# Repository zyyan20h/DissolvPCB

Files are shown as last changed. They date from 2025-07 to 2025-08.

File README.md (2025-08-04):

# DissolvPCB 
### Fully Recyclable Electronics with Liquid Metal Conductors and 3D-Printed PVA Substrates
DissolvPCB is a fully recyclable printed circuit board assembly (PCBA) manufacturing technique 
that utilizes affordable FDM 3D printing with Polyvinyl Alcohol (PVA) as a water-soluble substrate 
and eutectic gallium-indium (EGaIn) as the conductive material. 

This Github repository contains the Python macro component used during the DissolvPCB fabrication process. 
The macro enables users to design custom PCB assemblies using standard practices, then automatically
convert the design into a 3D model ready to be printed. Also included are some PCB design examples that 
were used for the demonstration of the DissolvPCB fabrication process. 
Listed below are the prerequisites and instructions on how to utilize this tool. 
Detailed instructions on the entire DisssolvPCB fabrication process can be found under [DissolvPCB Processs Details](DissolvPCB_Process_Details.md).

teaser_labelless

Please see the [paper](https://www.arxiv.org/abs/2507.22193) for more details on development, implementation, and evaluation of DissolvPCB, and if you use DissolvPCB in your work, please consider to cite the following paper:
```
@article{yan2025dissolvpcb,
  title={DissolvPCB: Fully Recyclable 3D-Printed Electronics with Liquid Metal Conductors and PVA Substrates},
  author={Yan, Zeyu and Hong, SuHwan and Hester, Josiah and Cheng, Tingyu and Peng, Huaishu},
  publisher = {Association for Computing Machinery},
  url = {https://doi.org/10.1145/3746059.3747604},
  year={2025}，
  booktitle = {Proceedings of the 38th Annual ACM Symposium on User Interface Software and Technology}
}
```

## Installation 

### Prerequisites
  - Python 3.0.0 or above
  - FreeCAD 1.0.0 or above
    - https://www.freecad.org/downloads.php
  - KiCAD 8.0.7 or above
    - https://www.kicad.org/download/

### KiCAD Libraries Installation
  - Add Symbol Library
    - Located in /libray/PVA_board.kicad_sym
    - Add by going to: Symbol Editor -> File -> Add Library
  - Add Footprint Library
    - Located in /library/PVA_board.pretty
    - Add by going to: Footprint Editor -> File -> Add Library
  - Copy 3D moddels to KiCAD 3D Models
    - Copy the folder /library/PVA_Board_3Dmodels into directory
    - Set Global Variable "KICAD_3DMODEL_DIR" to correct directory
      - Usually Located under C:\Program Files\KiCad\8.0\share\kicad\3dmodels
      - You can locate the direcotry by going to the KiCAD project window, then Preferences -> Configure Paths
   
## DissolvPCB Design in KiCAD
### PCB Schematic Design
  If you have imported the libraries as described above, the schematic design follows standard procedues.
  During the footprint assignment at the end of your schematic design procecss, verify that 
  footprints are from the PVA_Board library.
    
### PCB Layout Design
  To ensure compatibility with the DissolvPCB fabrication process, a few settings must be changed first. 
  The DRC settings can simply be imported from /KiCAD/DRC_Import_Prj/DRC_Import/DRC_Import.kicad_pcb, using the "Import Settings from Another Board" button under File -> Board Setup. 
  By importing "Design rule constraints", "Predefined track & via dimensions", and "Violation severities" (optional), 
  the PCB design will become compatible with the DissolvPCB fabrication process. (See attached below)
	432048682-aeb7e37b-99a9-4a01-ab0c-9ea9d6ce369a

## Macro Execution
FreeCAD has built-in support for Python macros. 
To run, open the Python script by going to File -> Open and open /Python/create.py.
Then, run the macro by going to Macro -> Run Macro. 
Note that the boolean process step at the end can take some time depending on the complexity of your design and your compute power. 
Therefore, it is recommended that you run the macro on a system with a more powerful CPU if possible.

### Macro Functions
The Python scripts contain code comments throughout to help users debug and modify. Overall, the 4 main steps of the macro includes:
- Trace & Pad Generation
- DissolvPCB Body Creation
- 3D Footprint Insertion
- Boolean Operation

Except for the Boolean Operation, these parts are independant of each other. 
Thus, it is possible to run any combination of of the first 3 as desired. 

*Note: If the boolean operation fails from an error relating to 'multiple bodies', you may have to enable a setting. 
Go to Edit -> Preferences -> Part/Part Design -> Experimental -> check "Allow multiple solids in Part Design Body by Defualt"

## Examples 

Some KiCAD Designs are provided, which are listed below.
Note that Circuit_sample_01, circuit_sample_02, and ESP_Speaker designs are directly compatible with the macro, and does not require any modifications to replicate our designs. 
  - /KiCAD/circuit_sample/circuit_sample_01
    - Hall Sensor & ATTiny85 design, used throughout the paper
      
  - /KiCAD/circuit_sample/circuit_sample_02
    - Identical Hall Sensor & ATTiny85 design, but with different board outline
	- /KiCAD/circuit_sample/recycled_driver
		- Motor driver circuit design, used to demonstrate the capabilities of the recycled PVA filament
  - /KiCAD/ESP_Breakout
    - Breakout board(s) designed to house the ESP32 board used for the ESP_Speaker Design
    - The version utilized on the paper is the "2mm_2row_esp_breakout" design
  - /KiCAD/ESP_Speaker
    - ESP32-based bluetooth speaker design.
    - The exact design used on the paper demo is "rev_2_ESP_Speaker_2row_esp"
    - Alternatively, a design with components only on one side is under "rev_3_ESP_Speaker_2row_esp"
      
  - /KiCAD/fidget
    - Fidget toy example used on the paper, utilizing a 3D circuit design process.


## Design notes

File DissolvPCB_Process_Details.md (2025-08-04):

# DissolvPCB 
### Fully Recyclable Electronics with Liquid Metal Conductors and 3D-Printed PVA Substrates
This document the full work flow of creating a circuit board based on the DissolvPCB process in detail, along with tips, recommendations, and general cautions. 
This guide will instruct users through the steps of printing and preparation, assembling, and recycling, as highlighted in the figure below. 

teaser_labelless

# DissolvPCB Printing & Preparation
## Materials 
- In addition to things like 3D printers and EGaIn, other materials and tools needed for the DissolvPCB fabrication process are:
	- PPE - Gloves, Goggles
 	- Wet wipes (Such as Clorox)
  	- Magnetic Stirrers
  	- Glass Beakers
  	- Scale
  	- Syringe
  	- Fine Tweezers
  	  
		

## DissolvPCB Printing
### PVA Nozzle 
- Size
  	- A nozzle size of 0.2 mm is recommended for the smallest possible feature size, trace dimensions, layer detail, etc.
  	- A 0.4 mm nozzle may be used, although some dimensions may have to be increased and the finest pitch components may not be as feasible.
  		In this case, 0.85 mm traces are recommended instead of the default 0.75 mm.
- Cleanup
    - Nozzle Storage
    	- After printing with PVA, it is recommended PLA is loaded into the filament in place and any leftover PVA be extruded out.
  		- As is standard, the unloaded PVA filament should be kept in a filament dryer.
    - Nozzle Cleanout
  		- In cases where the entire nozzle needs to be cleaned, it could be submerged in water to remove any remaining PVA.

### PVA Print Storage
- Moisture Control
    - Filament Dryer should be used whenever possible for the storage of filaments, prints, and finished circuits to avoid moisture damage.
    - If at any point of the DissolvPCB assembly the circuit gets moisture damaged, it can be reversed in most cases in a dryer. Slight changes like warping may remain to some degree.
		
## EGaIn Preparation 

### EGaIn Viscosity Control 
- Oxidation Level
	- The viscosity of the liquid metal is controlled by the oxidation level of EGaIn.
	- EGaIn is very liquid at room temperature. If a thicker consistency is desired, the EGaIn can be oxidized using the magnetic stirrer.
		(Over the air exposure with periodic stirring will work, just slower)
- Viscosity Control
	- EGaIn viscosity can be fine tuned by mixing unoxidized EGaIn in appropriate ratios until the desired consistency is achieved.
   
		

### EGaIn Storage and Collection 
- General Storage
	- EGaIn should be stored in neutral constainers, such as glass beakers.
		If EGaIn is being stored period of time longer than an hour, a lid is recommended to prevent unwanted oxidation.
	- For long term storage, plastic paint containers may be a good alternative.
		A good sealing lid is essential.

		

- Collection
	- In most cases, EGaIn can easily be collected using a syringe or a pipette.

   		
	- In rare cases where the EGaIn is too thick to be sucked into a syringe, the EGaIn may have to be scooped into the syringe bit by bit.
- EGaIn Recollection ('dump')
    - Having a small beaker of Sodium Hyroxide solution readily available is highly recommended.
    - Any excess EGaIn can be easily collected into one container, while the NaOH solution deoxidizes them, ready for recollection and reuse.
 
### Safety and Cautions
- PPE
	- Gloves and Goggles are a must.
 	- Lab coats may be desireable in case of spills.
- Cautions
	- Small bits of EGaIn may remain on any surface and can spread easily if caution is not taken.
 	- Wet wipes (as pictured) can be a great tool to pick up EGaIn on any surface for cleaning.
  	- Always keep a seperate station dedicated to anything involved with EGaIn.

# DissolvPCB Assembly
## EGaIn
### EGaIn Injection
- Syringe Tip
	- Make sure the tip is clear of any obstruction before attaching to a syringe.
	- The syringe tip can be stored in the NaOH solution after use to remove any leftover EGaIn.
- What is a 'good' injection?
    - A slightly concave shape is desired, as excessive EGaIn can cause shorts and spills.

	

### Safety & Cautions
- PPE
	- Gloves and Goggles are a must.
 	- Lab coats may be desireable in case of spills.
- Cautions
	- Be weary of potential spills being directed towards the body, especially the face.
 	- Slow, fine manipulation of the EGaIn syringe is recommended, as EGaIn injection takes little to no force.
	- Excessive injections on the print or syringe can be collected into the NaOH solution beaker.
 		Here, the wet wipes can be used to 'wipe' execessive EGaIn into the beaker.
	- When placing components later, checking the EGaIn for proper contact may be necessary.

## Component Assembly
### Component Placement
- Component can be gently seated into its respective sockets once EGaIn is injected.
	A light push may be needed to ensure proper seating.

 	
 
### Component PVA Glue 
- The purpose of PVA glue is to:
  - Hold components in place
  - Prevent EGaIn spills
- Cautions
  - PVA glue, especially ones with higher water content, may deform the circuit body slightly. 
  - Again, make sure there aren't any short circuits before the glue cures.
- After everything is finished, the circuit can be dried and kept using a filament drier.

  	

# DissolvPCB Recycling

## Component Recovery 

### Dissolving DissolvPCB Assemblies
- Any DissolvPCB assembly may be dissolved simply by dropping it into water.
  The dissolving process can be accelerated using warmer water temperatures and occasional stirring.

  	
   
### Component Recovery
- After DissolvPCB is completely dissolved in water, components can be simply plucked out of the PVA solution.
- Components then can be cleaned and dried, then be ready for reuse.

	

### Safety & Cautions
- PPE
	- Gloves and Goggles are a must.
 	- Lab coats may be desireable in case of spills.
- Cautions
	- Residual PVA and/or EGaIn may remain on surfaces. Take cautions to avoid contamination
    
## EGaIn Recovery 

### EGaIn Collection & De-Oxidation
- Leftover EGaIn can be de-oxidized and re-consolidated easily using a solution of NaOH.
- Afterwards, EGaIn can be collected using a pipette and stored safely until reuse.

  	

### Safety & Disposal 
- After the NaOH solution is used, the basic solution must be neutralized. A safe acidic solution, such as Citric Acid, may be used.
  
## PVA Recovery 

### PVA Recovery - Filter
- The PVA solution should be filtered in case any contaminents are present.
  This also guarentees a cleaner extrusion when recyling the PVA into filament.

	
  
### PVA Recovery - Drying
- The PVA solution can be transferred into a petri dish to dry. A hot plate can be used here to accelerate the drying.

	

### PVA Recovery - PVA Glue
- After a certain moisture content of the PVA solution is reached, it can be used as PVA glue for the next iteration of DissolvPCB.
- Storage of PVA glue in a capped syringe may be appropriate.

	
  
### PVA Recovery - PVA Filament
#### Raw PVA Material Collection
- Dried PVA Sheets
	- By drying the PVA solution all the way, sheets of PVA can be peeled from the container of choice.
		A slightly flexible container can be easier to peel.

	

- Moisture Control
	- Extrusion quality can be heavily impacted by moisture in the processing material.
 		Ensure the filament material is kept dry as possible.
   
- Sheet Processing
	- The PVA sheets should be cut into appropriate sizes for filament extrusion.

#### PVA Recovery - Filament Extrusion
- Extrusion Temperature
	- Extrusion temperature may vary between extruder machines.
		However, extruded material should be a mouldable clay consistency than a liquid.
	- Too low of a temperature can prevent the extruded filament from being stretched to the desired diameter.
	- Too high of a temperature may cause filament deformation and sticking.
   
	
  
 	- It may be helpful to have airflow over the filament to help it hold its shape after being stretched out
- Extrusion of crude filament
	- Depending on the quality of the PVA base material, the extruded filament may be of low quality (such as bubbling).
   	  In this case, the extruded filament needs to be re-cut and processed again for a high-quality filament.
   - If low quality first extrusion is expected, it may help to extrude thicker filament to reduce work in filament processing.
     
	

#### Safety & Cautions
- PPE
	- A mask is highly recommended, gloves may be helpful.
	- Make sure filament extrusion is done in a well-ventilated area.
 		A fume hood, if available, is recommended.

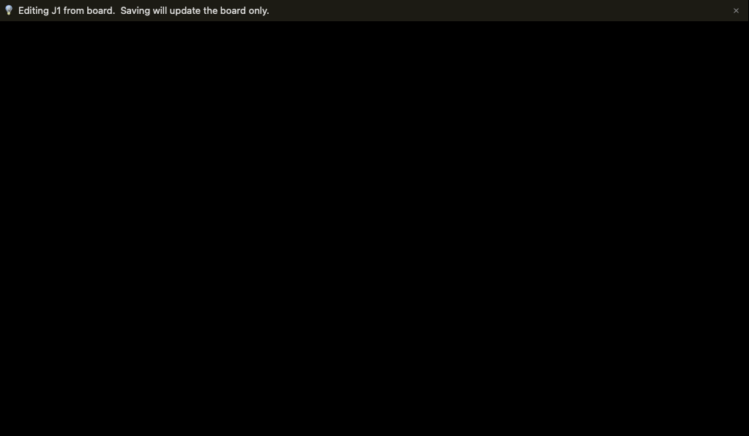
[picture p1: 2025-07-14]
KiCAD/ESP_Speaker/doubleLayer_trial/SAMTEC_USB-B-S-X-X-TH.png

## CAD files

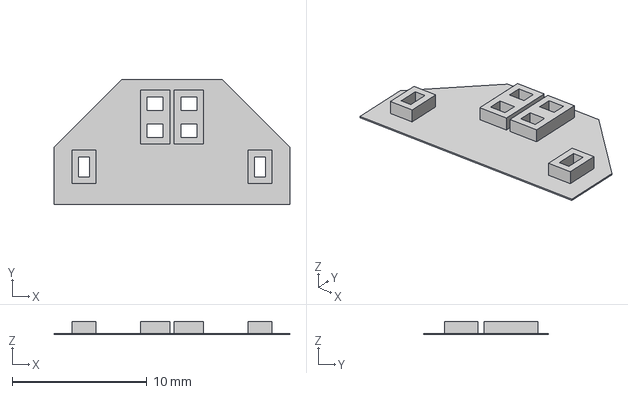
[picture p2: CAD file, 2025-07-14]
KiCAD/ESP_Speaker/doubleLayer_trial/usb-B v4.step
17.5 x 9.25 x 1.00 mm

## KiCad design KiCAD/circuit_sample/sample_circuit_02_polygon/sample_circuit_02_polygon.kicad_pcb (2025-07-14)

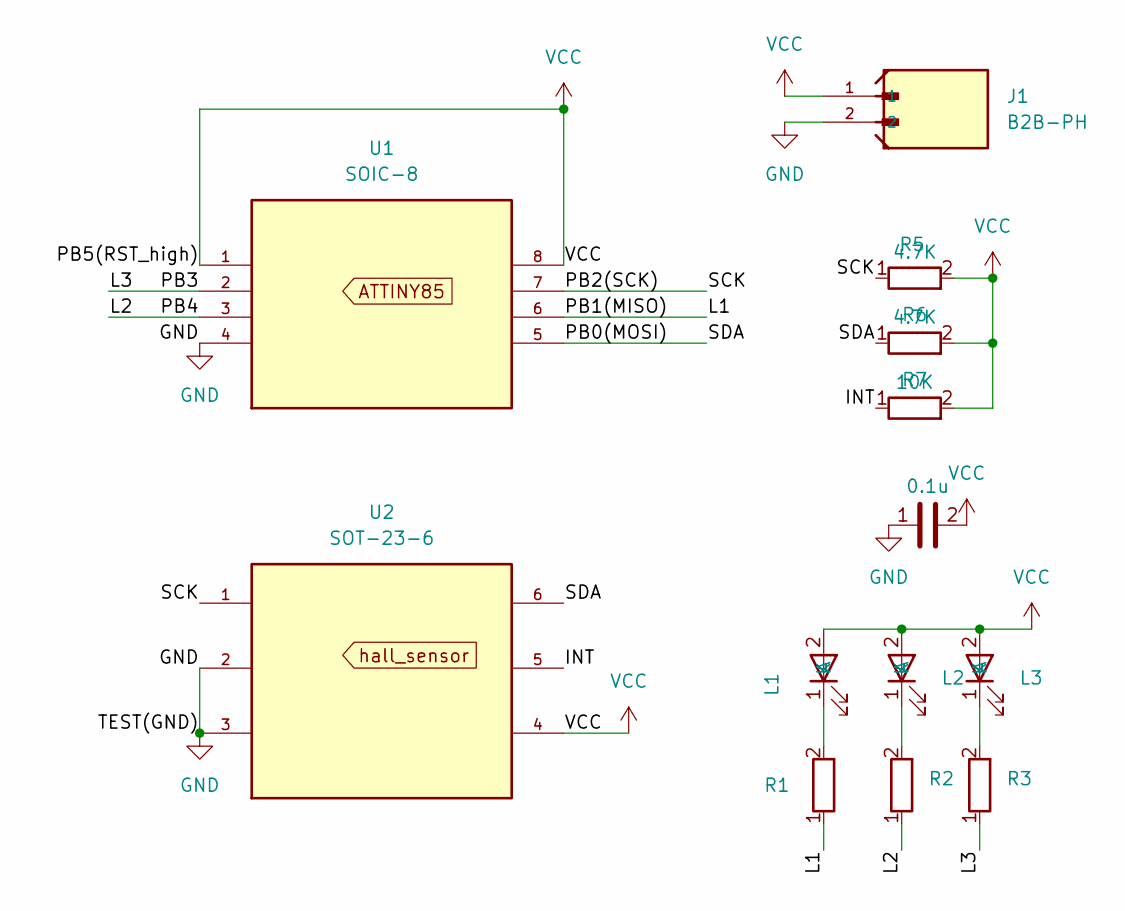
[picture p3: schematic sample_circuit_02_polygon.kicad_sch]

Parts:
C3: 0.1u; C-0805
J1: B2B-PH; JST_B2B-PH
L1, L2, L3: LED-1206
R1, R2, R3: R-0805
R5, R6: 4.7K; R-0805
R7: 10K; R-0805
U1: SOIC-8
U2: SOT-23-6

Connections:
/INT: R7.1, U2.5
/L1: R1.1, U1.6
/L2: R2.1, U1.3
/L3: R3.1, U1.2
/PB0(MOSI): R6.1, U1.5, U2.6
/PB2(SCK): R5.1, U1.7, U2.1
GND: C3.1, J1.2, U1.4, U2.2, U2.3
unnamed: L1.1 (K), R1.2
unnamed: L2.1 (K), R2.2
unnamed: L3.1 (K), R3.2
VCC: C3.2, J1.1, L1.2 (A), L2.2 (A), L3.2 (A), R5.2, R6.2, R7.2, U1.1, U1.8, U2.4

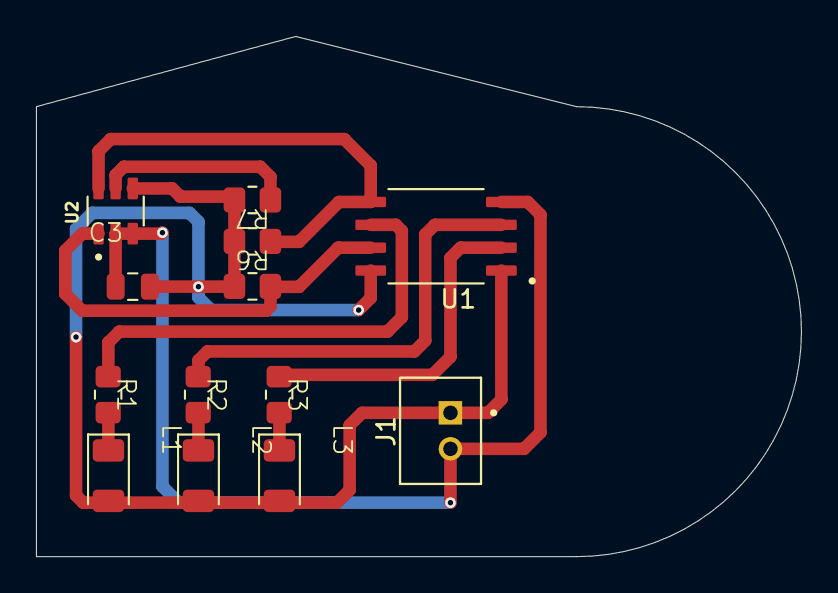
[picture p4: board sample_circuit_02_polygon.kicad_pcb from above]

Board: 2 copper layers, 42.5 x 28.9 mm, 13 parts (0 on the bottom side), 11 nets.

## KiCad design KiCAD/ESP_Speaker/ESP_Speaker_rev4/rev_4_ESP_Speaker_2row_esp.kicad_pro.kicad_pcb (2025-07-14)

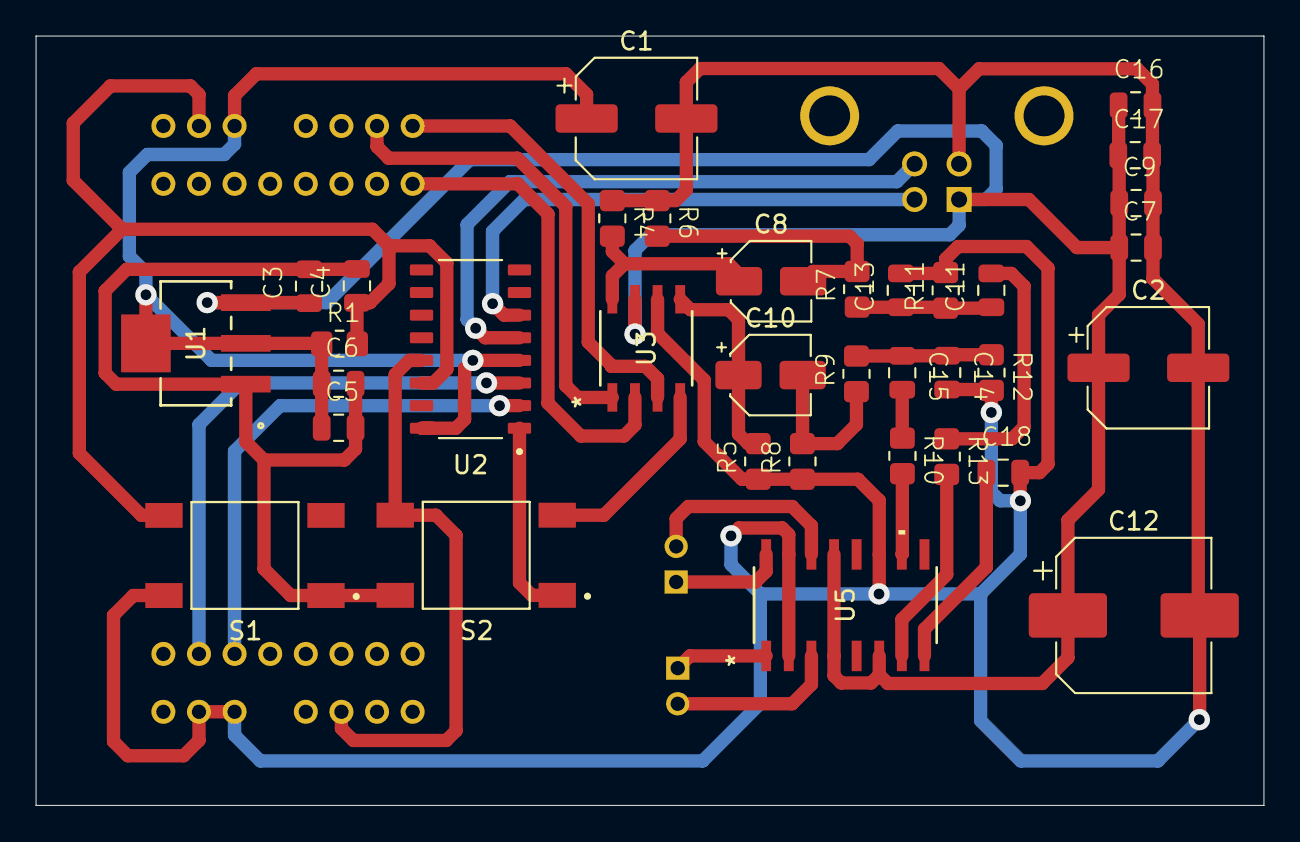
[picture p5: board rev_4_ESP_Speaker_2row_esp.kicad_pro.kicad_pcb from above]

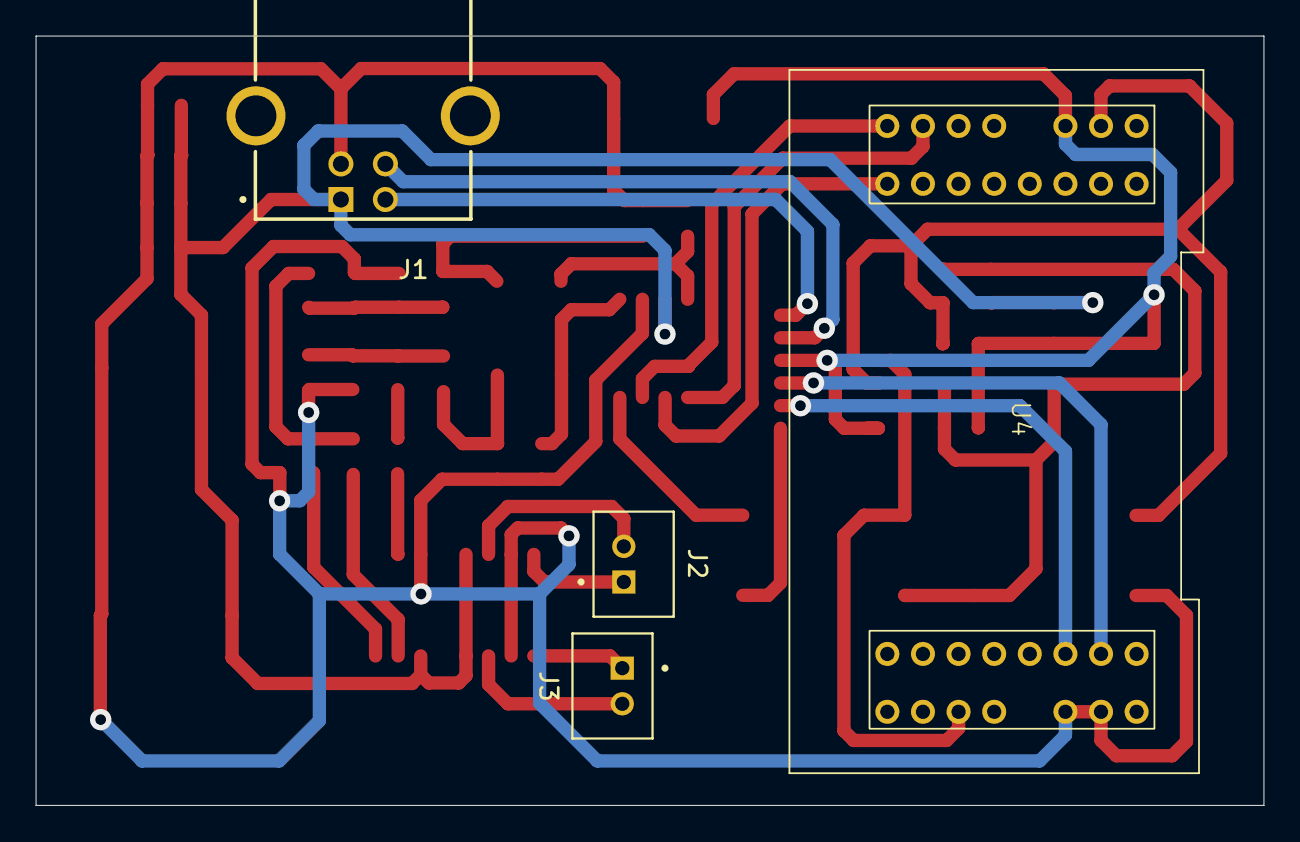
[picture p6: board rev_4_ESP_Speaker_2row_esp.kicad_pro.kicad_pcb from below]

Board: 2 copper layers, 69.0 x 43.2 mm, 39 parts (4 on the bottom side), 28 nets.

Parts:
C1, C2: 22uF; CP_Elec_6.3x5.4
C3, C5: 100nF; C-0805
C4, C7, C16, C17: 1uF; C-0805
C6, C9: 0.1uF; C-0805
C8, C10: 3.3uF; CP_Elec_4x5.4
C11, C15: 0.47uF; C-0805
C12: 470uF; CP_Elec_8x10.5
C13, C14: 6nF; C-0805
C18: .1uF; C-0805
J1: USB-B; SAMTEC_USB-B-S-X-X-TH
J2: Audio_R; JST_B2B-PH
J3: Audio_L; JST_B2B-PH
R1, R6, R8: 10k; R-0805
R4, R5: 267k; R-0805
R7, R9: 560; R-0805
R10, R13: 20k; R-0805
R11, R12: 22k; R-0805
S1, S2: 1571527-2; SW_4pin_SMD
U1: AMS1117; SOT_AMS_ADS-M
U2: CH340C; CH430C_SOP16
U3: CS4334-KSZ; CIR-SOIC-8_W150-M
U4: 2mm_2row_esp32_breakout
U5: PAM8403DR; SOIC_8403DR_PAM8403-M

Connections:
+3.3V: C1.1, C5.1, C6.1, R1.1, U1.2 (VOUT), U1.4 (EPAD), U2.4 (V3), U2.16 (VCC), U4.1 (3V3)
+5V: C2.1, C3.1, C7.1, C9.1, C12.1, C16.1, C17.1, J1.1 (VCC), U1.3 (VIN), U3.7 (VA), U5.4 (PVDD), U5.6 (VDD), U5.13 (PVDD)
/Audio-Amp/Audio_R: C14.1, C15.1, R9.2, R12.1
/Audio-Amp/Audo_L: C11.1, C13.1, R7.1, R11.1
/Audio-Amp/L+: J3.1, U5.1 (+OUT_L)
/Audio-Amp/L-: J3.2, U5.3 (-OUT_L)
/Audio-Amp/R+: J2.1, U5.16 (+OUT_R)
/Audio-Amp/R-: J2.2, U5.14 (-OUT_R)
/BCLK: U3.2 (DEM/SCLK), U4.11 (IO27)
/Data: U3.1 (SDATA), U4.13 (IO12)
/EN: C4.1, R1.2, S1.3, S1.4, U2.14 (~RTS), U4.2 (EN)
/IO0: S2.3, S2.4, U2.13 (~DTR), U3.4 (MCLK), U4.29 (IO0)
/RX_ESP: U2.2 (TXD), U4.21 (RXD0)
/TX_ESP: U2.3 (RXD), U4.20 (TXD0)
/WS: U3.3 (LRCK), U4.12 (IO14)
D+: J1.3 (D+), U2.5 (UD+)
D-: J1.2 (D-), U2.6 (UD-)
GND: C1.2, C2.2, C3.2, C4.2, C5.2, C6.2, C7.2, C9.2, C12.2, C13.2, C14.2, C16.2, C17.2, C18.2, J1.4 (GND), R4.1, R5.1, R6.1, R8.1, R11.2, R12.2, S1.1, S1.2, S2.1, S2.2, U1.1 (GND/ADJ), U2.1 (GND), U3.6 (AGND), U4.16 (GND), U4.17 (GND), U5.2 (PGND), U5.11 (GND), U5.15 (PGND)
unnamed: C8.2, R6.2, R7.2
unnamed: C10.2, R8.2, R9.1
unnamed: C11.2, R13.1
unnamed: C15.2, R10.1
unnamed: J1.S1 (SHIELD), J1.S2 (SHIELD)
unnamed: C8.1, R4.2, U3.8 (AOUTL)
unnamed: C10.1, R5.2, U3.5 (AOUTR)
unnamed: R13.2, U5.7 (INL)
unnamed: R10.2, U5.10 (INR)
unnamed: C18.1, U5.8 (VREF)

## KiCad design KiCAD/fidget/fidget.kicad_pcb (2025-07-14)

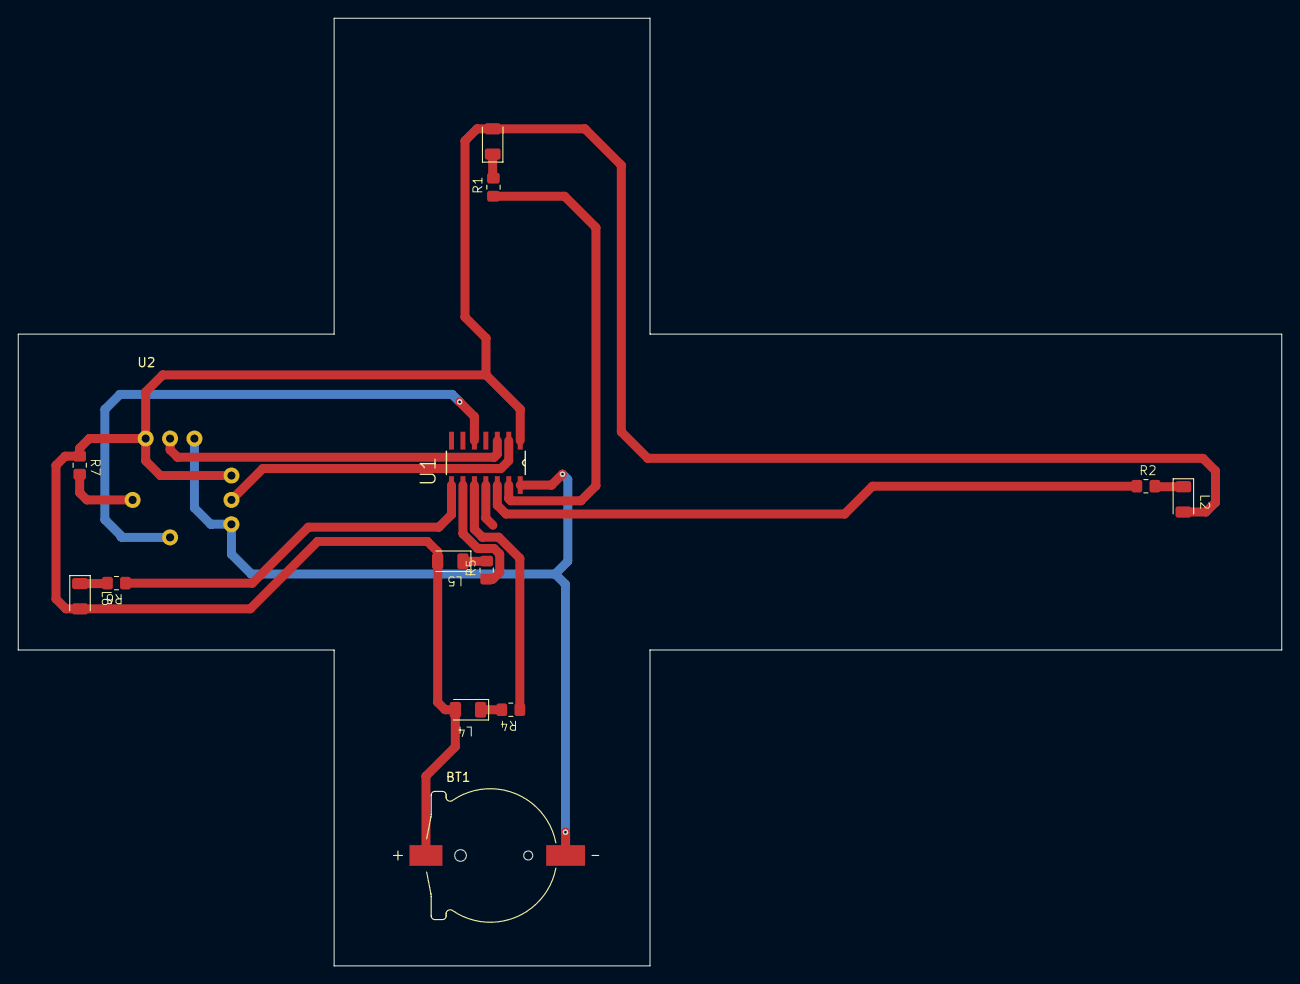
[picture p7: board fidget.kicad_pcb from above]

Board: 2 copper layers, 140.0 x 105.0 mm, 14 parts (0 on the bottom side), 16 nets.

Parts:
BT1: CH291-1220LF; BAT_CH291-1220LF
L1, L2, L4, L5, L6: LED-1206
R1, R2, R4, R5, R6, R7: R-0805
U1: SOIC-14
U2: COM-09032; Joystick

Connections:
/GND: BT1.N, U1.14, U2.H3 (H-), U2.V3 (V-)
/L1: R1.1, U1.13
/L2: R2.1, U1.12
/L4: R4.1, U1.10
/L5: R5.1, U1.9
/L6: R6.1, U1.8
/S1: U1.3, U2.V2 (V)
/S2: U1.2, U2.H2 (H)
/S3: U1.5, U2.Sb
/VCC: BT1.P, L1.2 (A), L2.2 (A), L4.2 (A), L5.2 (A), L6.2 (A), R7.1, U1.1, U2.H1 (H+), U2.V1 (V+)
unnamed: L1.1 (K), R1.2
unnamed: L2.1 (K), R2.2
unnamed: L4.1 (K), R4.2
unnamed: L5.1 (K), R5.2
unnamed: L6.1 (K), R6.2
unnamed: R7.2, U2.Sa

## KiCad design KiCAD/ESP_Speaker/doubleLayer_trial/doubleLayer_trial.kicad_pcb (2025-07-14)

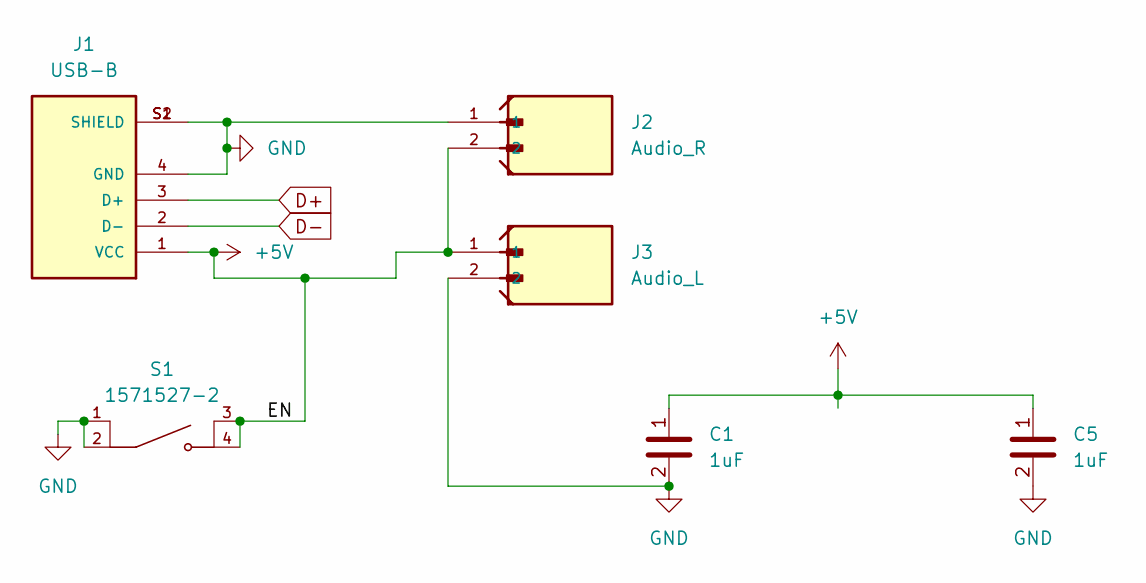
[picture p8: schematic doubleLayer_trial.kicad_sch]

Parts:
C1, C5: 1uF; C-0805
J1: USB-B; SAMTEC_USB-B-S-X-X-TH
J2: Audio_R; JST_B2B-PH
J3: Audio_L; JST_B2B-PH
S1: 1571527-2; SW_4pin_SMD

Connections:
+5V: C1.1, C5.1, J1.1 (VCC), J2.2, J3.1, S1.3, S1.4
D+: J1.3 (D+)
D-: J1.2 (D-)
GND: C1.2, C5.2, J1.4 (GND), J1.S1 (SHIELD), J1.S2 (SHIELD), J2.1, J3.2, S1.1, S1.2

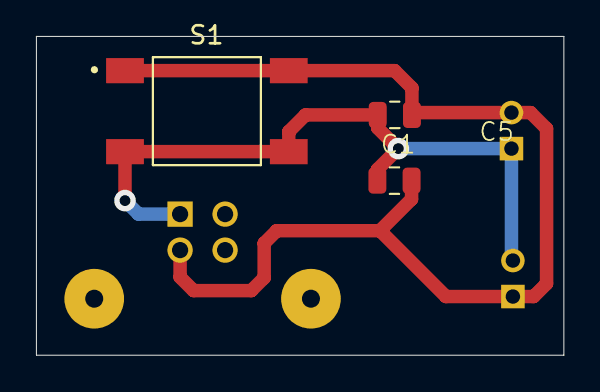
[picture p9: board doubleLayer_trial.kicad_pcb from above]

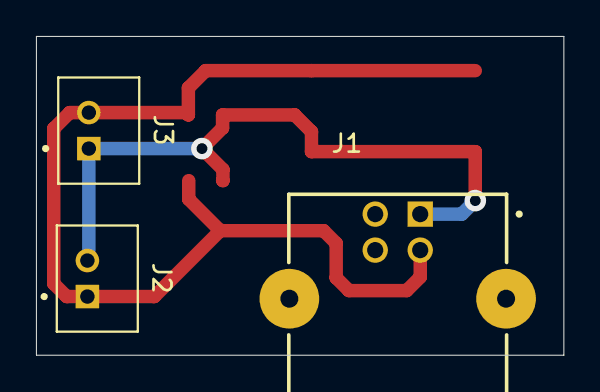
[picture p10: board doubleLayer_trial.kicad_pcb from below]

Board: 2 copper layers, 29.3 x 17.7 mm, 6 parts (3 on the bottom side), 2 nets.

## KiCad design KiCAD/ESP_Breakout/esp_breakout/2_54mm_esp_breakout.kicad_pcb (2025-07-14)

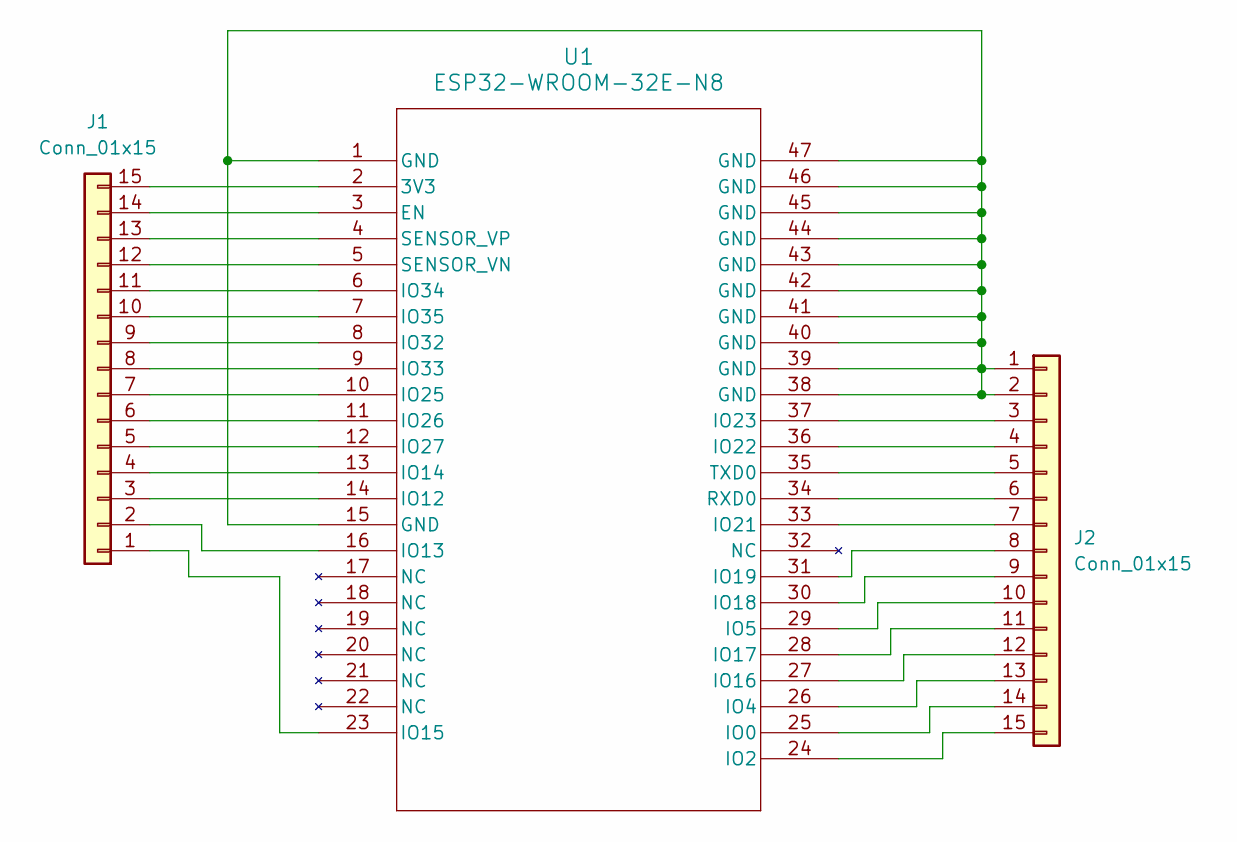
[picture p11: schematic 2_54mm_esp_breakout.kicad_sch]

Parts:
J1, J2: Conn_01x15; PinHeader_1x15_P2.54mm_Vertical
U1: ESP32-WROOM-32E-N8; ESP32­WROOM­32E_EXP

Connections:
unnamed: J1.1, U1.23 (IO15)
unnamed: J1.2, U1.16 (IO13)
unnamed: J1.3, U1.14 (IO12)
unnamed: J1.4, U1.13 (IO14)
unnamed: J1.5, U1.12 (IO27)
unnamed: J1.6, U1.11 (IO26)
unnamed: J1.7, U1.10 (IO25)
unnamed: J1.8, U1.9 (IO33)
unnamed: J1.9, U1.8 (IO32)
unnamed: J1.10, U1.7 (IO35)
unnamed: J1.11, U1.6 (IO34)
unnamed: J1.12, U1.5 (SENSOR_VN)
unnamed: J1.13, U1.4 (SENSOR_VP)
unnamed: J1.14, U1.3 (EN)
unnamed: J1.15, U1.2 (3V3)
unnamed: J2.1, J2.2, U1.1 (GND), U1.15 (GND), U1.38 (GND), U1.39 (GND), U1.40 (GND), U1.41 (GND), U1.42 (GND), U1.43 (GND), U1.44 (GND), U1.45 (GND), U1.46 (GND), U1.47 (GND)
unnamed: J2.3, U1.37 (IO23)
unnamed: J2.4, U1.36 (IO22)
unnamed: J2.5, U1.35 (TXD0)
unnamed: J2.6, U1.34 (RXD0)
unnamed: J2.7, U1.33 (IO21)
unnamed: J2.8, U1.31 (IO19)
unnamed: J2.9, U1.30 (IO18)
unnamed: J2.10, U1.29 (IO5)
unnamed: J2.11, U1.28 (IO17)
unnamed: J2.12, U1.27 (IO16)
unnamed: J2.13, U1.26 (IO4)
unnamed: J2.14, U1.25 (IO0)
unnamed: J2.15, U1.24 (IO2)

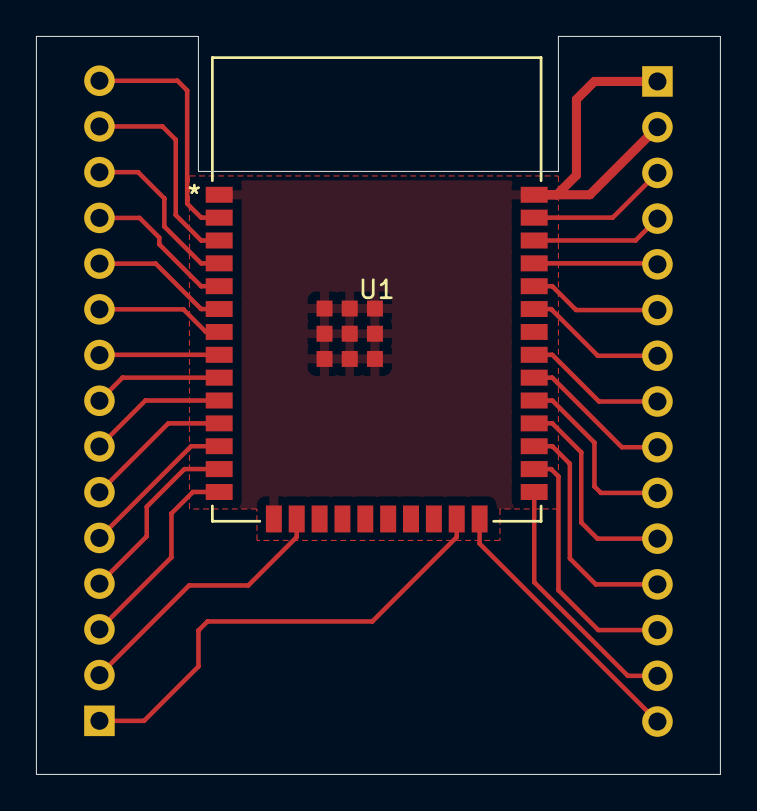
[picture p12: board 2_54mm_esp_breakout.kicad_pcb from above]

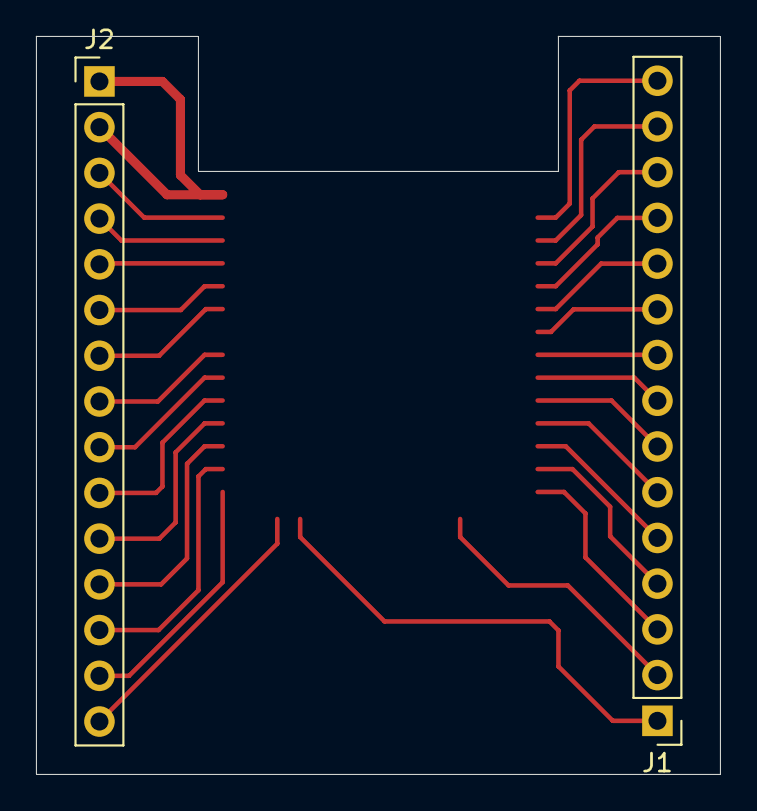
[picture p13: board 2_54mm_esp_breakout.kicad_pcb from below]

Board: 2 copper layers, 38.0 x 41.0 mm, 3 parts (2 on the bottom side), 29 nets.

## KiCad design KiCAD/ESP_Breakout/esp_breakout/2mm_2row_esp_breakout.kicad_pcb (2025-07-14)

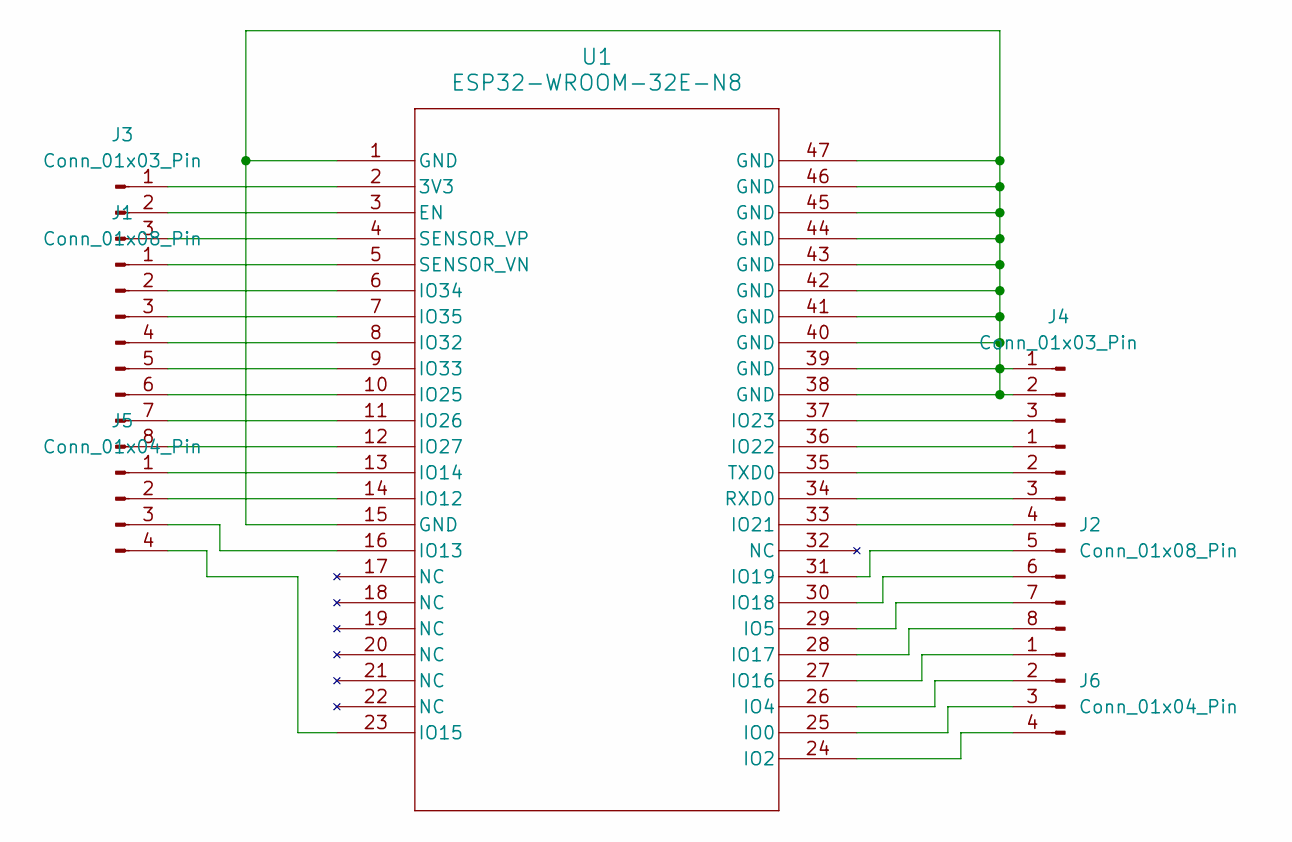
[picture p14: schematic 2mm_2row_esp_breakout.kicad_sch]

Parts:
J1, J2: Conn_01x08_Pin
J3, J4: Conn_01x03_Pin
J5, J6: Conn_01x04_Pin
U1: ESP32-WROOM-32E-N8; ESP32­WROOM­32E_EXP

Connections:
unnamed: J1.1, U1.5 (SENSOR_VN)
unnamed: J1.2, U1.6 (IO34)
unnamed: J1.3, U1.7 (IO35)
unnamed: J1.4, U1.8 (IO32)
unnamed: J1.5, U1.9 (IO33)
unnamed: J1.6, U1.10 (IO25)
unnamed: J1.7, U1.11 (IO26)
unnamed: J1.8, U1.12 (IO27)
unnamed: J2.1, U1.36 (IO22)
unnamed: J2.2, U1.35 (TXD0)
unnamed: J2.3, U1.34 (RXD0)
unnamed: J2.4, U1.33 (IO21)
unnamed: J2.5, U1.31 (IO19)
unnamed: J2.6, U1.30 (IO18)
unnamed: J2.7, U1.29 (IO5)
unnamed: J2.8, U1.28 (IO17)
unnamed: J3.1, U1.2 (3V3)
unnamed: J3.2, U1.3 (EN)
unnamed: J3.3, U1.4 (SENSOR_VP)
unnamed: J4.1, J4.2, U1.1 (GND), U1.15 (GND), U1.38 (GND), U1.39 (GND), U1.40 (GND), U1.41 (GND), U1.42 (GND), U1.43 (GND), U1.44 (GND), U1.45 (GND), U1.46 (GND), U1.47 (GND)
unnamed: J4.3, U1.37 (IO23)
unnamed: J5.1, U1.13 (IO14)
unnamed: J5.2, U1.14 (IO12)
unnamed: J5.3, U1.16 (IO13)
unnamed: J5.4, U1.23 (IO15)
unnamed: J6.1, U1.27 (IO16)
unnamed: J6.2, U1.26 (IO4)
unnamed: J6.3, U1.25 (IO0)
unnamed: J6.4, U1.24 (IO2)


Board: 2 copper layers, 39.5 x 23.2 mm, 7 parts (0 on the bottom side), 29 nets.

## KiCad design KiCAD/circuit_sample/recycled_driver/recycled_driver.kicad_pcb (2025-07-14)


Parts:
C1, C3: C; CP_Radial_D5.0mm_P2.00mm
D1: D; D_DO-41_SOD81_P7.62mm_Horizontal
J1: Conn_01x02_Pin; PinHeader_1x02_P2.54mm_Vertical
J2, J3: Conn_01x04_Pin; PinSocket_1x04_P2.54mm_Vertical
R1: R; D_DO-41_SOD81_P7.62mm_Horizontal
U1: MX1508; mx1508

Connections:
/vcc: C3.1, D1.1 (K), R1.2, U1.1 (VCC1), U1.5 (VCC2)
/vin: C1.1, J1.1, R1.1, U1.4 (VDD1), U1.8 (VDD2)
GND: C1.2, C3.2, D1.2 (A), J1.2, U1.10 (AGND2), U1.11 (PGND2), U1.14 (AGND1), U1.15 (PGND1)
unnamed: J2.1, U1.2 (INA1)
unnamed: J2.2, U1.3 (INB1)
unnamed: J2.3, U1.6 (INA2)
unnamed: J2.4, U1.7 (INB2)
unnamed: J3.1, U1.9 (OUTB2)
unnamed: J3.2, U1.12 (OUTA2)
unnamed: J3.3, U1.13 (OUTB1)
unnamed: J3.4, U1.16 (OUTA1)


Board: 2 copper layers, 23.7 x 26.1 mm, 8 parts (0 on the bottom side), 11 nets.
